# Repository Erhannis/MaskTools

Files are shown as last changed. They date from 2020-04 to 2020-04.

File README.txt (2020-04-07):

Tools to help people sew masks for doctors etc. dealing with the COVID-19 pandemic.

Read the header in mask_tools.scad for printing instructions.  (The bare minimum: PRINT AT -0.08 HORIZONTAL EXPANSION, or probably nothing will fit together.  And/or, use the fast.curaprofile profile to print things fast.  Print all the files with "MAIN" in the name.  Of those, print two of the ones that say "print_two" in the name.)

Released into the public domain.

-Erhannis

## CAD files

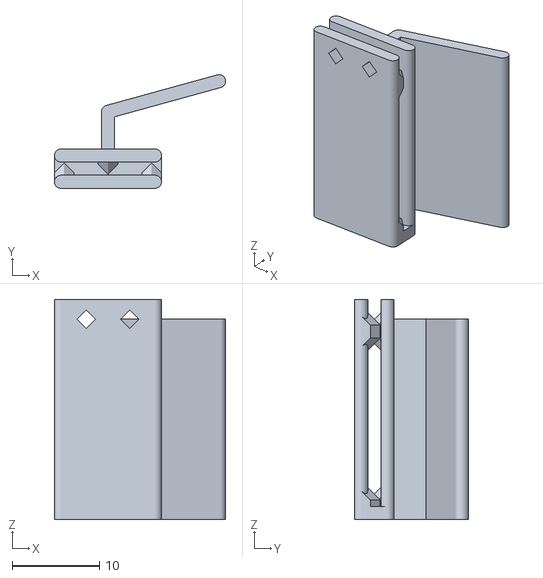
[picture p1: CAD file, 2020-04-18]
MAIN_hook_clip_print_twelve.stl
19.6 x 13.0 x 25.1

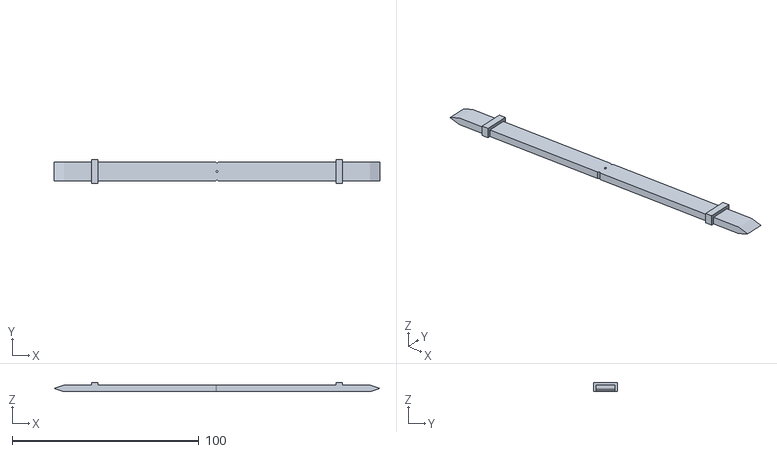
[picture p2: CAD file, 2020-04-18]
MAIN_pleat_bridge_pier.stl
174.8 x 13.0 x 5.00

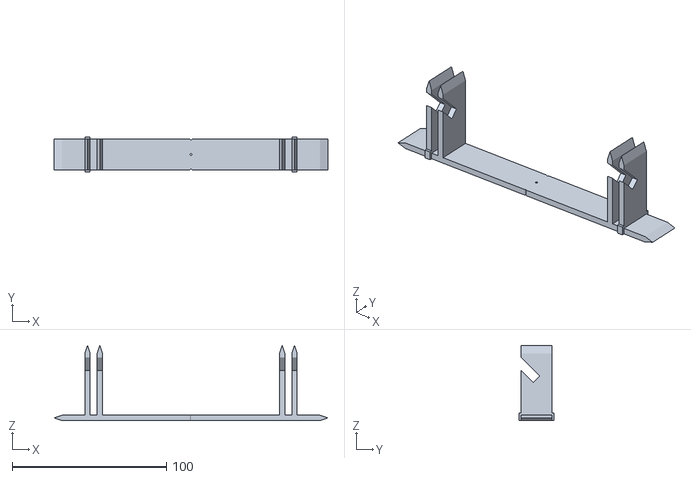
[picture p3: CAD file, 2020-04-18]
MAIN_pleat_bridge_b.stl
177.8 x 23.0 x 48.8

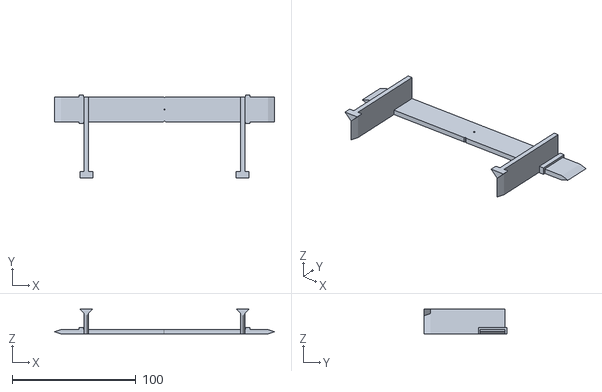
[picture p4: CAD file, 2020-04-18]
MAIN_pleat_bridge_a.stl
177.8 x 66.8 x 20.0

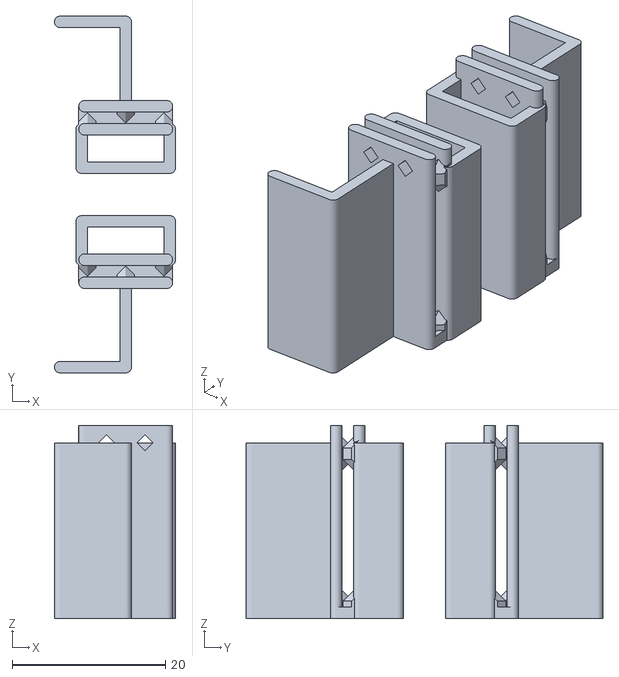
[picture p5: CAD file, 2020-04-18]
MAIN_pier_clip_pair.stl
15.8 x 46.5 x 25.1

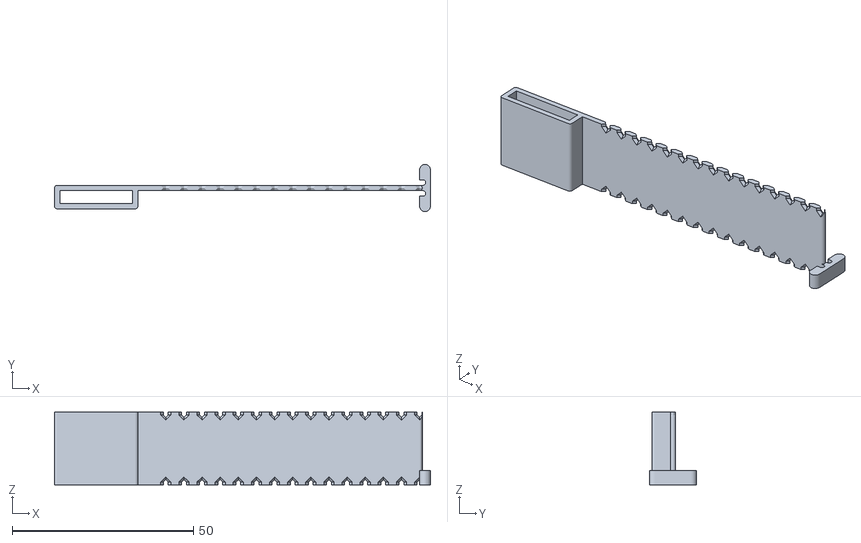
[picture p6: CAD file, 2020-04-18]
MAIN_pleat_rack_a_print_two.stl
103.7 x 13.0 x 20.0

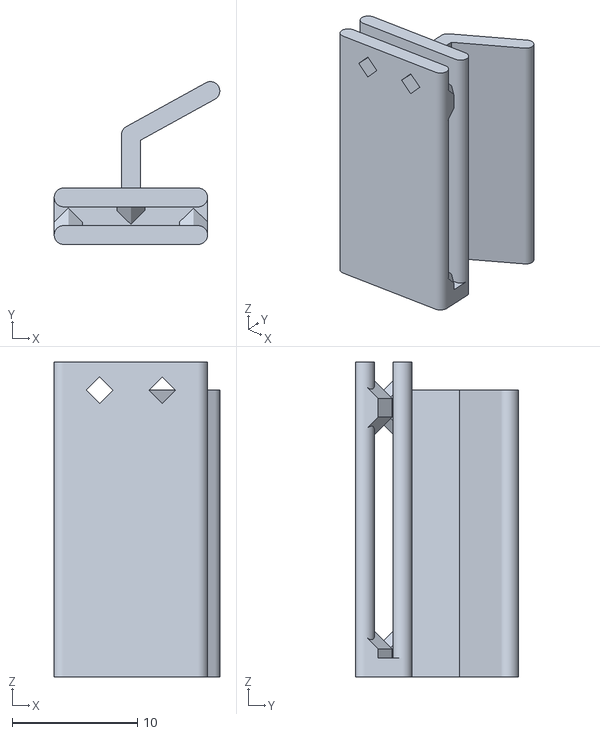
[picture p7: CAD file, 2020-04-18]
MAIN_hook_clip_short_may_print_twelve.stl
13.2 x 13.0 x 25.1

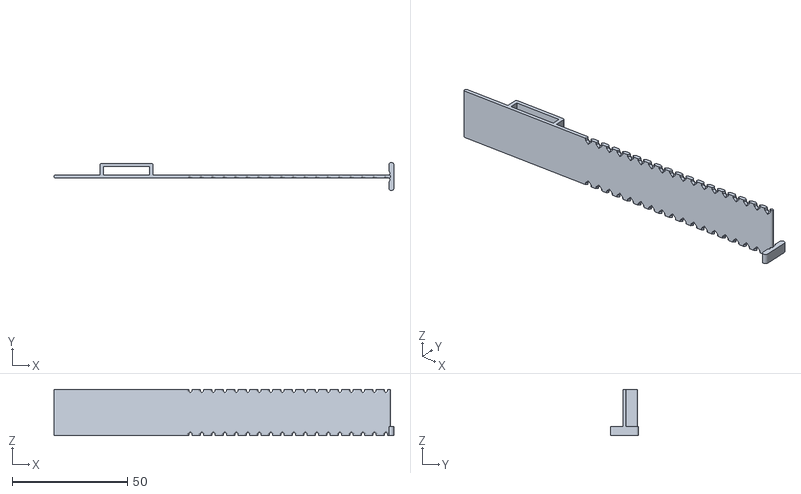
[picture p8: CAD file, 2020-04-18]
MAIN_pleat_rack_b_print_two.stl
147.8 x 12.2 x 20.0

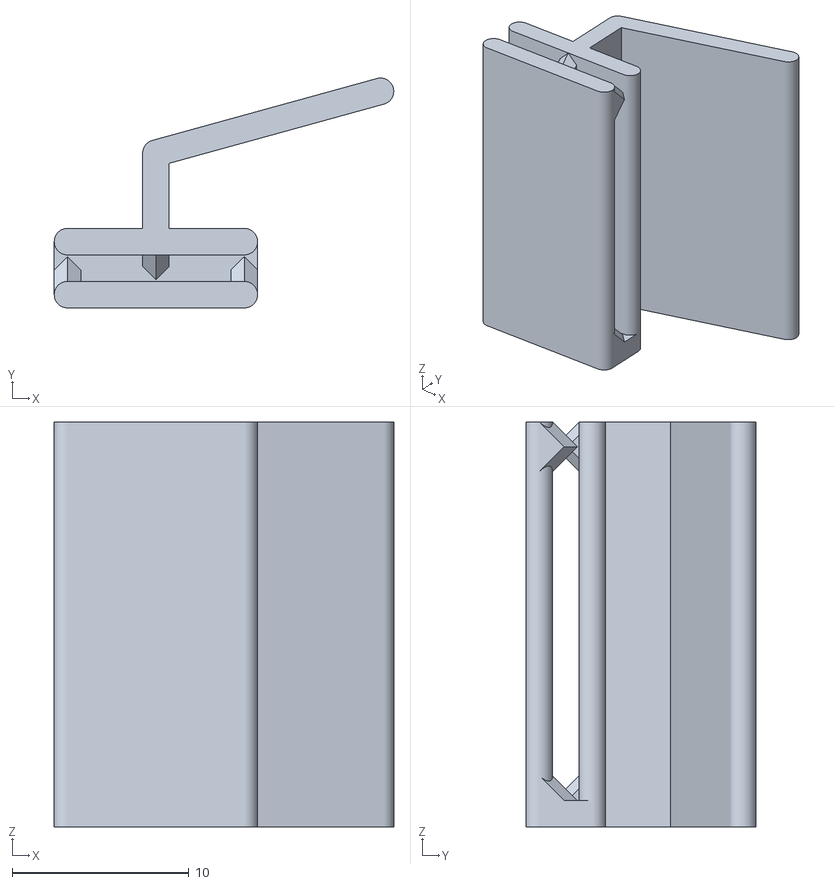
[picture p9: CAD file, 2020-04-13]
MAIN_hook_clip_print_six.stl
19.2 x 13.0 x 22.9

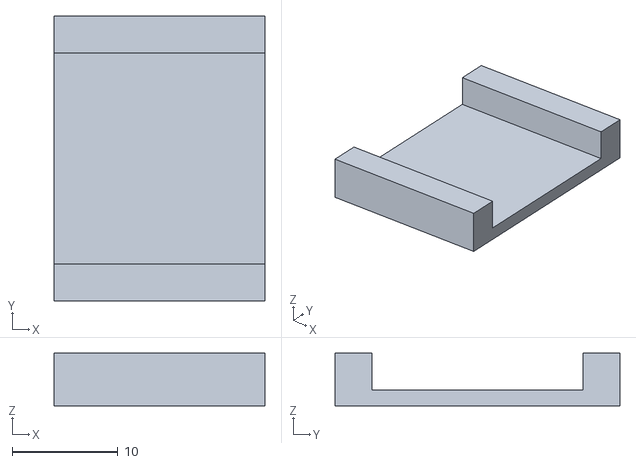
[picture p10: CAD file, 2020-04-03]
MAIN_pleat_bridge_support.stl
20.0 x 27.0 x 5.00

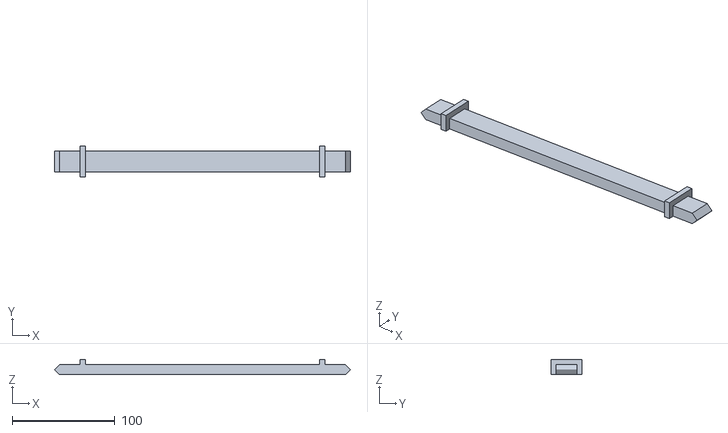
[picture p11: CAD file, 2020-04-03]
MAIN_cutting_rig_big_bridge.stl
288.6 x 30.0 x 15.0

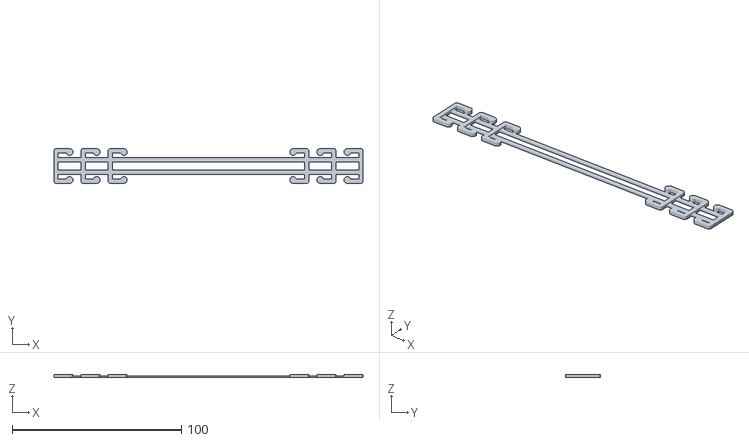
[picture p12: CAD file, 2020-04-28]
strap_helper.stl
182.5 x 20.5 x 2.00

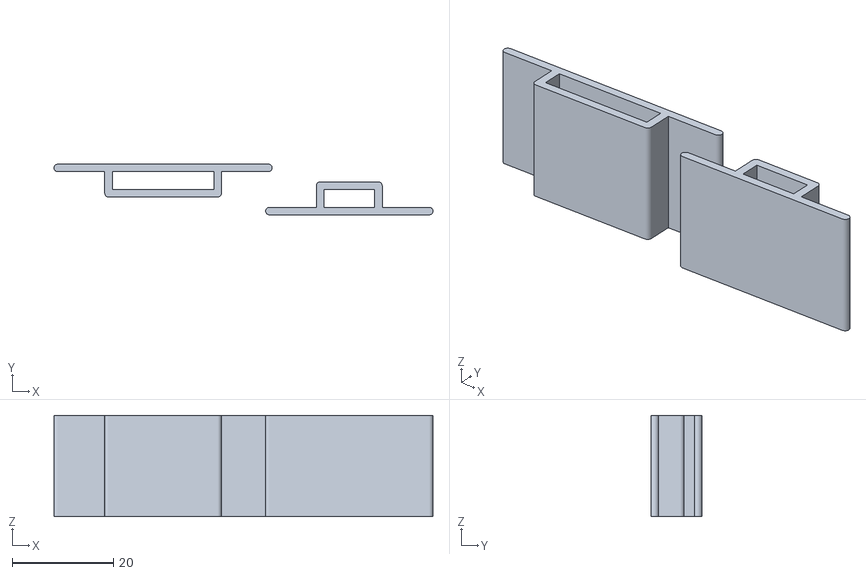
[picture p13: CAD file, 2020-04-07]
fit_test_sockets.stl
74.7 x 10.0 x 20.0

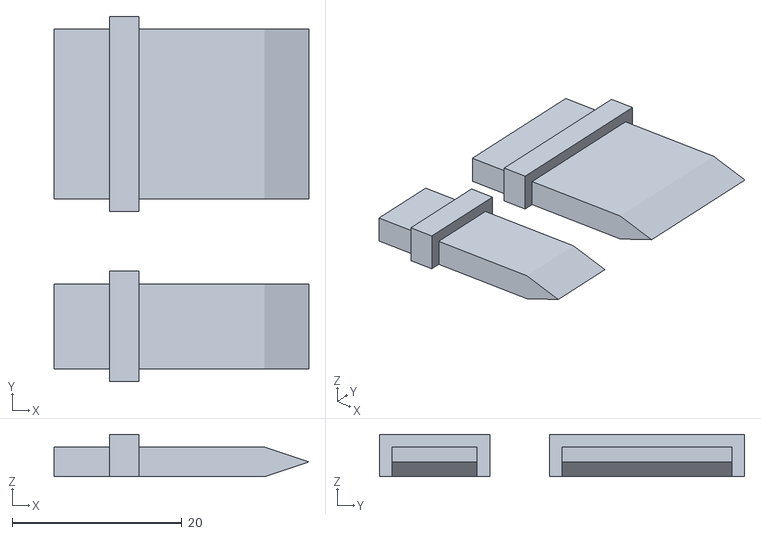
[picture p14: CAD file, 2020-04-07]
fit_test_pegs.stl
30.0 x 43.0 x 5.00

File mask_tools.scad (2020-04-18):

/**
Tools to help make emergency masks out of fabric.
Templates, forms, etc.

How to use (and other stuff) : https://www.youtube.com/watch?v=6Kmpcf4xn78

To print different things, basically just solo different elements.  (Put a "!" in front
of the element in question.  And/or remove the "*".)  Not super well organized, sorry.

Printing:
I printed with a 0.4mm nozzle.
I've added Cura profile files to the repo:
  * pleat_racks.curaprofile to print the pleat racks
  * structural_rectilinear.curaprofile to print the short things you can fit facing east-west and north-south
  * structural_diagonal.curaprofile to print the long things you have to print at a 45* angle
    * or the short things you print at a 45* angle anyway
  * fast.curaprofile - this one is kinda all-in-one.  You can print an entire set of pleat racks/bridges
      with this - but I recommend that you turn down the temperature to 200 after the infill slabs are done,
      or you're gonna get a mess of stringing in inconvenient places.  You can do this manually on your printer
      at the correct time, or you can use
      Cura > Extensions > Post Processing > Modify GCode > Add A Script > Change At Z
      with height of 4 (approx), and Change Extruder 1 Temp to 200. 

If you use one of these profiles (as appropriate), you should be good.  However, here are most (all?)
of the settings that went into them:

Settings:
* EVERYTHING IS PRINTED AT -0.08mm HORIZONTAL EXPANSION.  (A Cura setting.)
    If this is merely ignored, almost certainly things will not fit together.
    Your printer may print slightly differently, though - you may want to experiment with
    different settings and the "Fit tests" block I have down below.
* For speed, print without the top or bottom layers.
  * Most of the settings listed here are for the purposes of speed.
* If you print anything at a 45* angle, e.g. to fit on a normal bed, you should
    make sure the infill crisscrosses the part, rather than running lengthwise
    and across - the part is stronger with crisscrossing infill.
    You may have to mess with Cura's "infill line directions".
      Infill Line Directions = [0,90,180,270]
* I had trouble printing infill at 0.4mm layer height with a 0.4mm nozzle
* Here's how I often printed things:
  * Nozzle 0.4mm
  * PLA
  * -0.08 Horizontal Expansion
  * -0.24 Initial Layer Horizontal Expansion (to help reduce bulging at base)
    * ...Or so I thought; but I saw -0.16 when I checked my settings just now.
  * Infill: zig zag
  * Infill line width: 0.8
  * No top or bottom faces (Top/Bottom Thickness = 0)
  * 3 shells (Wall Thickness)
  * (Usually not worth the effort) Same outer wall speed as inner wall speed (Outer Wall Speed = 30.0mm/s)
    * Note that you have to deburr the joining spots thoroughly, in this case
        Basically take all the corners off the joiner peg
  * Pleat rack:
    * Bridges:
      * 0.2mm layer height (my printer had problems with the infill at higher heights)
    * Racks:
      * 0.4mm layer height (there's no infill, so my printer was fine with it)
  * Cutting rig:
    * No brim or skirt (no room)
    * Everything at 45*
    * Infill Line Directions = [0,90,180,270]
    * 0.2mm layer height
  * Maybe some stuff I forgot, sorry

Assembly video: https://youtu.be/a_CLPrR-0fA

* Stuff to consider:
  * You will probably need to deburr the corner edges of the buildplate-facing
      surface of any joiners - inside sockets, bottom corner edges of pegs.
  * If you're having trouble gettings a peg in a socket, grab the peg stick
      as close above the peg as possible (probably immediately above the
      stopper) with pliers, place the socket on an e.g. table, brace your
      pliers hand on the table, grip tightly with the pilers, and tap the
      pliers down with something heavy and hard, like a large hammer.  (Not
      TOO hard, mind you - they'll snap if you hit them really hard, or bend
      them in the wrong direction, though these things are quite sturdy in the
      direction of their length.)
  * Or, a slightly less risky way I discovered, was to do the pliers thing, but
      then place the socket-end in your palm and pull on the pliers with that
      hand's fingers, like one of those springy hand exercise devices.  I'll
      have to post a video at some point.
  * When using the pleat rack, you can move the cloth even while clamped -
      you may have to kinda shimmy the rack open and closed a bit while pulling
      gently on the cloth.


Current list of recommended parts:
  Ruler spacer, 9 inch (push type, probably) x2
  Cutting rig
  Pleat rack
*/

use <deps.link/erhannisScad/misc.scad>
use <deps.link/scadFluidics/common.scad>

$fn=60;
EPS = 1e-100;
BIG = 1000;

INCH = 25.4;

//SX = 3*INCH;
//SY = 2*INCH;
SX = 9*INCH;  // This is how wide the mask is
SY = 6*INCH;  // This is how tall the mask is
STEP_SZ = 2;
STEP_SZ_BIG = STEP_SZ*1.5;
PLEAT_SY = 0.5*INCH;
MIDDLE_SY = 1.75*INCH;
LIP = 3;
PLEAT_STEPS_INSET = 0.5*INCH; // Like, how much fabric should hang off the ends

BRACE_SX = LIP/2;
VOID_INTERVAL = 10.5;

TEMPLATE_SZ = 5; //TODO Might need to be bigger

module centerPleat() {
  difference() {
    union() {
      translate([0,0,STEP_SZ/2]) cube([SX,MIDDLE_SY,STEP_SZ],center=true);
      translate([0,0,-STEP_SZ_BIG/2]) cube([SX,MIDDLE_SY-PLEAT_SY*2,STEP_SZ_BIG],center=true);
    }
    *intersection() {
      difference() {
        cube(BIG,center=true);
        for (dx=[-20:1:20]) translate([dx*VOID_INTERVAL,0,0]) cube([BRACE_SX,BIG,BIG],center=true);
      }
      cube([SX-LIP*2,MIDDLE_SY-PLEAT_SY*2-LIP*2,BIG],center=true);
    }
  }
}

*union() { // Pleat steps
  // Center
  centerPleat();
  
  // Edges
  //cmirror([0,1,0])
  *translate([0,MIDDLE_SY*1.1,0]) union() {
    difference() {
      mirror([0,0,1]) union() {
        centerPleat();
        translate([0,0,-(STEP_SZ_BIG-STEP_SZ)/2]) cube([SX,LIP*2,STEP_SZ+STEP_SZ_BIG],center=true);
      }
      OYp();
    }
  }
}
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

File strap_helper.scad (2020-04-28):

use <deps.link/erhannisScad/misc.scad>
use <deps.link/scadFluidics/common.scad>

$fn=60;
EPS = 1e-10;
BIG = 1000;

INCH = 25.4;

CATCH_INTERVAL = 16;
CATCH_COUNT = 3; // Per side
CATCH_DEPTH = 8;
CATCH_OUT = 4;
CATCH_NUB_D = 4;

RX = 60; // Per half...kinda.  Mess with it until things are the right length.
//ANGLE_ZONE = 10; // Per half
ANGLE_ZONE = 5;
ANGLE = 0;
MIRROR_POINT = ([-cos(ANGLE),sin(ANGLE)]*ANGLE_ZONE);
WIDTH = 10;
THICK = 2.5;

BEND_WIDTH = WIDTH+CATCH_OUT+THICK;
//BEND_WIDTH = WIDTH;
BEND_TRANSITION = 5;

TALL_SZ = 2;
SHORT_SZ = 1;

cmirror(MIRROR_POINT) translate(-MIRROR_POINT) {
  // Frame
  linear_extrude(height=SHORT_SZ) difference() {
    union() { // Solid
      // Bend
      if (ANGLE == 0) {
        channel(from=[-ANGLE_ZONE,0],to=[ANGLE_ZONE,0],d=BEND_WIDTH);
      } else {
        channel($fn=1000,from=MIRROR_POINT,to=[ANGLE_ZONE,0],dir1=-MIRROR_POINT,dir2=[-1,0],d=BEND_WIDTH);
      }
      // Transition
      channel(from=[ANGLE_ZONE-EPS,0],to=[ANGLE_ZONE+BEND_TRANSITION+EPS,0],d1=BEND_WIDTH,d2=WIDTH);
      // Straight bit
      channel(from=[ANGLE_ZONE+BEND_TRANSITION-EPS,0],to=[RX,0],d=WIDTH);
    }
    union() { // Removed
      // Bend
      if (ANGLE == 0) {
        channel(from=[-ANGLE_ZONE,0],to=[ANGLE_ZONE,0],d=BEND_WIDTH-THICK*2);
      } else {
        channel($fn=1000,from=MIRROR_POINT,to=[ANGLE_ZONE,0],dir1=-MIRROR_POINT,dir2=[-1,0],d=BEND_WIDTH-THICK*2);
      }
      // Transition
      channel(from=[ANGLE_ZONE-EPS,0],to=[ANGLE_ZONE+BEND_TRANSITION+EPS,0],d1=BEND_WIDTH-THICK*2,d2=WIDTH-THICK*2);
      // Straight bit
      channel(from=[ANGLE_ZONE+BEND_TRANSITION-EPS,0],to=[RX,0],d=WIDTH-THICK*2);
    }
  }
  // Catches
  linear_extrude(height=TALL_SZ) {
    for (dx = [(RX-CATCH_INTERVAL*(CATCH_COUNT-1)):CATCH_INTERVAL:RX]) {
      translate([dx,0]) {
        cmirror([0,1]) for (ps = [
          [[0,0],[0,WIDTH/2+CATCH_OUT]],
          [[0,WIDTH/2+CATCH_OUT],[-CATCH_DEPTH,WIDTH/2+CATCH_OUT]]
        ]) {
          channel(from=ps[0],to=ps[1],d=THICK,cap="circle");
        }
        cmirror([0,1]) translate([-CATCH_DEPTH,WIDTH/2+CATCH_OUT-CATCH_NUB_D/2+THICK/2]) circle(d=CATCH_NUB_D);
      }
    }
  }
}

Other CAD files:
cutting_rig_small_bridge_print_two.stl
1_inch_corner_spacer.stl
9_inch_corner_spacer.stl
9_inch_spacer_print_two.stl
cutting_rig_edge_brace_print_two.stl
xacto_aligner.stl

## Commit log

2020-03-31 New repo; mask tools, for helping to make emergency COVID-19 masks from fabric. Currently have prototype pleat steps.
    [mask_tools.scad, pleat_steps.stl, pleat_steps_center.stl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]
2020-04-01 Several iterations into a mask template
    [mask_tools.scad]
2020-04-01 Added pleat bridge. Currently printing a test.
    [mask_tools.scad, pleat_bridge_a.stl, pleat_bridge_b.stl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]
2020-04-01 DANG IT, missed an offset
    [mask_tools.scad, pleat_rack_a.stl, pleat_rack_b.stl]
2020-04-01 Added a ruler spacer
    [9_inch_spacer.stl, mask_tools.scad]
2020-04-01 Decided I didn't want a caltrop
    [9_inch_spacer.stl, mask_tools.scad]
2020-04-01 Added cutting rig
    [9_inch_spacer.stl, cutting_rig_big_bridge.stl, cutting_rig_edge_brace.stl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]
2020-04-01 Tweaked demo layout of pleat rack
    [mask_tools.scad]
2020-04-01 Applied results of testing to pleat rack. 1. Increased cloth slop. 2. Chopped off excess pier. 3. Added idle slot. 4. Made assembly narrower, to leave room for the sewing machine foot. 5. Increased p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
    [mask_tools.scad, pleat_bridge_a.stl, pleat_bridge_b.stl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]
2020-04-02 Oops...I used the wrong dimension for the cutting rig edge brace length. This is why I (sometimes remember to) print stubby partial test pieces first.
    [cutting_rig_edge_brace.stl, mask_tools.scad]
2020-04-02 Added an xacto-aligner, for making it easier to cut corners. I mean, cut fabric in the corner of e.g. a ruler.
    [mask_tools.scad, xacto_aligner.stl]
2020-04-02 Ok, apparent THIS time I've done the math right
    [cutting_rig_edge_brace.stl, mask_tools.scad]
2020-04-02 Increased blade depth to 2mm. Not sure if that improved it or made it worse - now it kinda, stutters? In either case the fabric tries to bunch up in front of the aligner.
    [mask_tools.scad, xacto_aligner.stl]
2020-04-02 Fiddling with stuff
    [mask_tools.scad]
2020-04-02 Prepared cutting rig parts for flat printing.
    [mask_tools.scad]
2020-04-02 Added 10mm to HANDLE_B_SX
    [mask_tools.scad]
2020-04-02 Removed pier bridge B
    [mask_tools.scad]
2020-04-02 Decreased hook interval. Rejiggered rack lengths; should adjust automatically for different cloth sizes and hook intervals, now, to still have the center segment be centered. Hopefully.
    [mask_tools.scad]
2020-04-02 Cut pier bridge in half.
    [mask_tools.scad]
2020-04-02 Added center marking on bridges
    [mask_tools.scad]
2020-04-02 Widened rack by 1/2in
    [mask_tools.scad]
2020-04-02 Added center markings to rack pieces
    [mask_tools.scad]
2020-04-02 Tweaked comments
    [mask_tools.scad]
2020-04-02 Updated pleat rack to print flat
    [mask_tools.scad, pleat_bridge_a.stl, pleat_bridge_b.stl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]
2020-04-02 Added holding tabs to pleat rack
    [mask_tools.scad, pleat_rack_b.stl]
2020-04-03 Added printing instructions
    [mask_tools.scad]
2020-04-03 Added corner spacers
    [1_inch_corner_spacer.stl, 9_inch_corner_spacer.stl, mask_tools.scad]
2020-04-03 Forgot to narrow the idle slot
    [mask_tools.scad, pleat_bridge_b.stl]
2020-04-03 Added catch nub to bridge B
    [mask_tools.scad]
2020-04-03 Added bridge B support block
    [mask_tools.scad, pleat_bridge_support.stl]
2020-04-03 Update docs
    [cutting_rig_big_bridge.stl, cutting_rig_small_bridge.stl, mask_tools.scad]
2020-04-03 Fixed support block
    [mask_tools.scad, pleat_bridge_support.stl]
2020-04-04 Why can't I get this handle size right?!? It just keeps overshooting or something, but I can't figure out why!
    [mask_tools.scad, pleat_bridge_a.stl, pleat_bridge_b.stl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]
2020-04-04 Updated docs
    [mask_tools.scad]
2020-04-04 Shortened bridge A's catch nub.
    [mask_tools.scad, pleat_bridge_a.stl]
2020-04-04 Angled pleat hooks out, so they can be spaced closer together. I think it works better, now!
    [mask_tools.scad, pleat_rack_a.stl, pleat_rack_b.stl]
2020-04-05 Flipped bridge socket to account for increased height
    [mask_tools.scad, pleat_rack_a.stl]
2020-04-05 Messing with docs. Made the spacer thinner again; seems to work fine.
    [9_inch_spacer.stl, mask_tools.scad]
2020-04-05 Oops, forgot I fixed the triangle
    [9_inch_spacer.stl, mask_tools.scad]
2020-04-06 Added Cura printing profiles
    [mask_tools.scad]
2020-04-06 Made names more explanatory
    [MAIN_9_inch_spacer_print_two.stl, MAIN_cutting_rig_big_bridge.stl, MAIN_cutting_rig_edge_brace_print_two.stl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]
2020-04-07 Trying to streamline usage again
    [9_inch_spacer_print_two.stl, cutting_rig_big_bridge.stl, cutting_rig_edge_brace_print_two.stl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]
2020-04-07 Messing with multiple pleats
    [mask_tools.scad]
2020-04-07 Revert "Messing with multiple pleats"
    This reverts commit 10f22090e07aa0f4f9f89ea3783fd04a56f4ebc2.
    [mask_tools.scad]
2020-04-07 Undoing 3-pleat stuff I accidentally committed
    [mask_tools.scad]
2020-04-07 I was having trouble fitting things together, so I added fit tests and updated fast.curaprofile with more (negative) horizontal expansion. Also added video links.
    [fit_test_pegs.stl, fit_test_sockets.stl, mask_tools.scad]
2020-04-09 Tweaked docs
    [mask_tools.scad]
2020-04-13 Working on hook clips
    [hook_clip.stl, mask_tools.scad]
2020-04-13 Possible first test of hook clip
    [MAIN_hook_clip_print_six.stl, MAIN_pleat_rack_a_print_two.stl, hook_clip.stl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]
2020-04-13 Actually kinda works
    [MAIN_pleat_rack_b_print_two.stl, mask_tools.scad]
2020-04-17 I think I was working on the hooks or something
    [MAIN_hook_clip_print_twelve.stl, MAIN_hook_clip_short_may_print_twelve.stl, MAIN_pleat_rack_a_print_two.stl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]
2020-04-18 Tweaked clips and stuff
    [MAIN_hook_clip_print_twelve.stl, MAIN_hook_clip_short_may_print_twelve.stl, MAIN_pier_clip_pair.stl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]
2020-04-28 Forgot to commit the strap helper file
    [strap_helper.scad, strap_helper.stl]
